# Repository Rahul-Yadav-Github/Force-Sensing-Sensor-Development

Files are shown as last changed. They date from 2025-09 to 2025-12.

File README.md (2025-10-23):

# Multi-Sensitivity Soft Tactile Sensor using Flexible Mechanical Metamaterials






---

## Project Overview

**Project Title:** Implementation of Flexible Mechanical Metamaterials Enabling Soft Tactile Sensors with Multiple Sensitivities at Multiple Force Sensing Ranges  
**Course Code:** CP302 — Honours Project  
**Institution:** Indian Institute of Technology Ropar  
**Department:** Mechanical Engineering  

**Team Members:**  
- **Rahul Yadav** — 2022MEB1334  
- **Sumer Mohan Singh Bassi** — 2022MEB1351  

**Supervisor:** Dr. Prabhat K. Agnihotri  

---

## Abstract

This project focuses on developing a **Multi-Sensitivity Soft Tactile (MST)** sensor using **flexible mechanical metamaterials**.  
The goal is to design and simulate a sensor capable of providing **multiple sensitivities across different force ranges**, overcoming the limitations of traditional single-sensitivity tactile sensors.

The sensor employs a **heterogeneous multi-layered metamaterial structure** with tunable stiffness properties, integrated with a **magnetic-based transduction mechanism** for force measurement.  
Simulations are conducted using **COMSOL Multiphysics**, combining *Solid Mechanics*, *Magnetic Fields*, and *Deformed Geometry* modules to model the mechanical and magnetic coupling behavior.

---

## Objectives

- Develop a mathematical and simulation framework for multi-sensitivity tactile sensing  
- Model a multi-layer metamaterial structure with programmable stiffness  
- Validate sensitivity and force range using multiphysics simulations  
- Demonstrate **step-by-step locking behavior** in a hierarchical structure  
- Prepare for future physical prototyping using TPU 3D printing  

---

## Methodology Summary

### 1. Mathematical Modeling
- Derived sensitivity equations based on **magnetic field variation with force**  
- Modeled metamaterial layers as **spring systems in series**  
- Established **stiffness hierarchy condition** for sequential deformation  

### 2. Simulation Framework
Implemented in **COMSOL Multiphysics** using:
- **Solid Mechanics Module:** Simulate deformation of TPU-based metamaterial  
- **Magnetic Fields Module:** Analyze field variation from embedded magnets  
- **Deformed Geometry Module:** Couple mechanical deformation with magnetic response  

### 3. Validation
Simulation outputs (force–displacement and magnetic variation plots) were validated against literature (Mohammadi et al., *Sci. Rep.*, 2021).

**Target sensitivities and ranges:**
| Layer | Sensitivity (N⁻¹) | Force Range (N) |
|:---|:---:|:---:|
| 1 | 0.26 | 0.9 |
| 2 | 0.08 | 4.8 |
| 3 | 0.03 | 16.2 |

---

## CAD Design

The metamaterial **unit cell** and **three-layer assembly** were modeled in SolidWorks and exported as STL files for fabrication and analysis.

- **Material:** Thermoplastic Polyurethane (TPU), Shore Hardness A85  
- **Design Parameters:**  
  - θ = (25°, 33°, 37°)  
  - t = (0.6, 1.0, 1.4) mm  
  - h = (2.0, 2.8, 3.5) mm  
--- 

## Repository Contents
- `docs/` → Project report and references  
- `cad_design/` → STL files and renders of the metamaterial design  
- `comsol_model/` → Multiphysics simulation model and results

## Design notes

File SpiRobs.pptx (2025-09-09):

## SpiRobs

Overview

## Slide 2

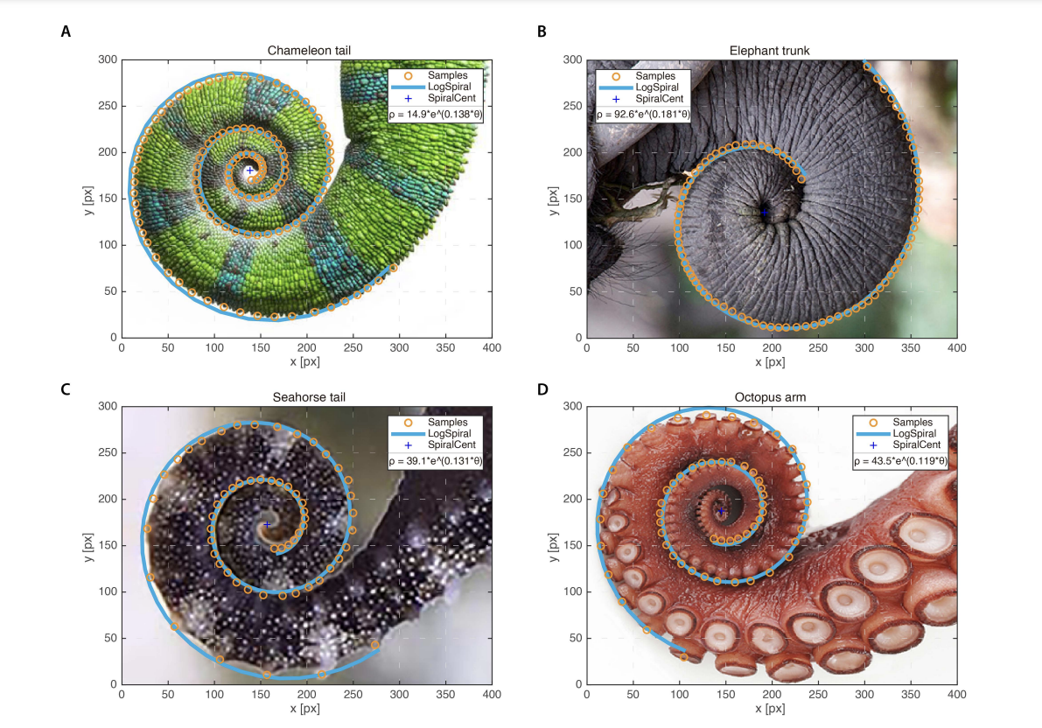
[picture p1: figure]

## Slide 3

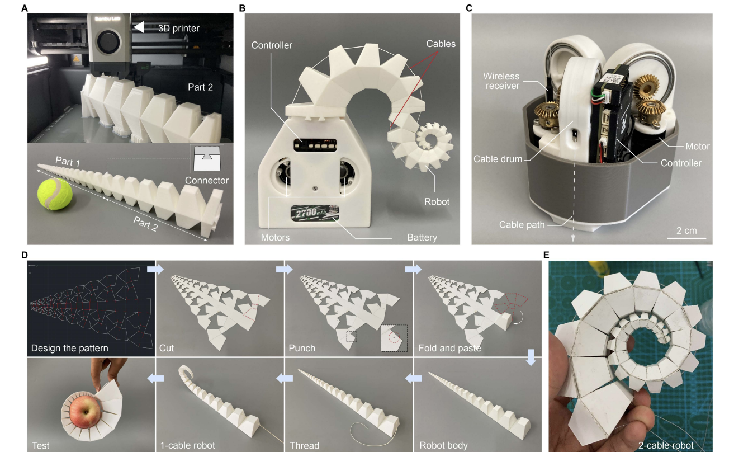
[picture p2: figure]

## Paper 1 Overview

- replicate the logarithmic spiral
- actuated by cables, which allows for fast and life-like movements.
- miniaturized gripper, a manipulator mounted on a drone, and multi-robot arrays.

## Existing Designs Problems

- different actuation methods, including pneumatic16–18 and cable driven, most of these prototypes can only produce arc-shaped bends with a limited curvature at the tip.
- use of soft materials (such as silicone) can increase the bending range and improve flexibility, this may result in wrinkling and buckling under large actuation forces, which, in turn, means failure to maintain a firm grasp.
- passive deformation caused by interacting with objects, However, these robots can typically only produce a single repetitive pattern (such as bend and release).

## What is required

- passive deformation caused by interacting with objects.
- ‘‘universal’’ strategies for reaching, grasping, and transporting objects of different shapes and from different positions (in contrast to rigid robots, albeit at the cost of high complexity for planning and control).

## Two Principles

- universal (across scales) design based on discretizing and uncurling the logarithmic spiral.
- Discretizing the Spiral - Instead of treating the spiral as a continuous smooth curve, the researchers break it into small connected sections (or discrete segments).
- Uncurling Mechanism - When the spiral is uncurling, these discrete segments move relative to each other in a coordinated manner.
- grasping strategy, inspired by the octopus
- controlling the curling/uncurling motion using cables
- passive deformation upon contact to adapt to objects of variable shapes and sizes (e.g., cup, pen, egg, strawberry, pineapple, and more;

## Design of SpiRobs

- Logarithmic Spiral
- Discretization
- Elastic Layer
- Taper Angle
- Conclusions are drawn for fixed length and tip diameter
- The smaller the taper angle, the larger the workspace
- At the same time, the larger the taper angle, the smaller the diameter of the smallest object that can be grasped and the larger the maximum load capacity.
- Taking the robot with a taper angle of 15 as an example, it can grasp objects whose diameters vary by two orders of magnitude (from 5.6 to 115 mm) and weigh roughly 260 times the weight of the robot (38.4 g selfweight and 10 kg load capacity

## Bioinspired grasping strategy

- Octopus- it progressively uncurls and straightens curled arms to reach the target. After making contact with the object, the arm keeps uncurling on the surface of the object to align the suckers.

## Automation

- To automate the grasping, they propose a method to detect contact with an object as well as a simple rule (piece-wise linear actuation) to control the cable forces by relating them directly to the object’s position.
- The threshold for detection was set through multiple experiments, and this simple mechanism was shown to be capable of detecting even the slightest contact; e.g., with a feather.

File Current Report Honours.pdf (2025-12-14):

# Honours Project Report Course Code: CP304

# Implementation of Flexible Mechanical Metamaterials Enabling Soft Tactile Sensors with Multiple Sensitivities at Multiple Force Sensing Ranges

### Team Members: Rahul Yadav (2022MEB1334) Sumer Bassi (2022MEB1351)

### Supervisor: Dr Prabhat K. Agnihotri Department: Mechanical Indian Institute Of Technology Ropar

### November 25, 2025

## Contents

1 Abstract | 4
2 Introduction | 4
3 Mathematical Theory and Formulations | 4
4 Background / Literature Review | 8
5 Problem Statement/Aim | 10
6 Methodology | 11

7 CAD Design and Modeling | 13
8 COMSOL Multiphysics Simulation Results | 15
9 Evolution of Methodology and Coupling Challenges | 25
10 Neccessary Plots for further calculations | 28
10.3 Normalized Magnetic Flux Density Change vs Magnet Displacement . . . | 29

### 11 Extraction of Layer Stiffness ki and Sensitivity Si from Simulation Data 31

12 Comparison Plot | 36
13 Future Work | 37
14 Conclusion | 38

## 1 Abstract

This project focuses on the development of a novel Multi-sensitivity Soft Tactile (MST) sensor based on flexible mechanical metamaterials. The primary objective is to design, model, and simulate a sensor that provides multiple sensitivities across different force sensing ranges, overcoming the traditional limitation of single-sensitivity tactile sensors. The proposed design utilizes a heterogeneous multi-layered structure with tunable stiffness properties, integrated with magnetic-based transduction method for force measurement.
The mechanical metamaterial structure consists of collapsible layers that exhibit stepby-step locking behavior, enabling different sensitivity regimes at various force magnitudes. This project involves CAD design, mathematical modeling, and COMSOL Multiphysics simulation of the metamaterial structure, aiming to demonstrate the feasibility of creating tactile sensors with programmable sensitivity characteristics for applications in robotics, prosthetics, and human-machine interaction.

## 2 Introduction

Tactile sensing is a fundamental requirement for advanced robotic systems, prosthetic devices, and human-machine interfaces. Traditional tactile sensors are typically designed with fixed sensitivity and operate within a predetermined force range, limiting their versatility in real-world applications. The need for adaptive tactile sensing capabilities has grown significantly with the advancement of soft robotics and the demand for more sophisticated human-robot interactions.
Modern applications such as robotic manipulation, texture identification, slip detection, and in-hand manipulation require tactile sensors capable of operating with different sensitivities across multiple force ranges. Current soft tactile sensors face inherent trade-offs between sensitivity and sensing range, where high sensitivity is achieved at narrow force ranges or low sensitivity across wide force ranges.
This project addresses these limitations by developing a novel approach based on flexible mechanical metamaterials that can provide multiple predetermined sensitivities at different force sensing ranges. The approach is inspired by human tactile sensing capabilities, where the skin’s multi-layered structure with varying stiffness properties enables sophisticated touch perception.
The current phase of development involves designing, modeling, and simulating a Multi-sensitivity Soft Tactile (MST) sensor that utilizes mechanical metamaterials as the force transfer medium, integrated with magnetic-based transduction for displacement measurement and force calculation.

## 3 Mathematical Theory and Formulations

### 3.1 Fundamental Sensitivity Definition

Based on the original research by Mohammadi et al. (2021), the core mathematical foundation of the MST sensor begins with the definition of sensitivity in terms of magnetic field variation with respect to applied force. The sensitivity S is mathematically defined as:

S =

∆B/B0
∆F

[N

−1
] | (1)

where:
- S = Sensitivity of the sensor (inverse Newtons)
- ∆B = Change in magnetic field magnitude (Tesla)
- B0 = Initial magnetic field without applied force (Tesla)
- ∆F = Change in applied force (Newtons)

This fundamental equation establishes the relationship between the measurable magnetic field changes and the applied forces, forming the basis for all subsequent calculations.

### 3.2 Multi-Layer Mechanical Model

### 3.2.1 Spring Model Analogy

The metamaterial structure can be mathematically modeled as a system of springs in series, where each unit cell i in block j acts as a spring with stiffness kji. For a single block with i layers, the force-displacement relationship for each unit cell follows Hooke’s law:

Fi = ki

- di | (2)

where:
- Fi = Force acting on the i th unit cell (N)
- ki = Stiffness of the i
th unit cell (N/mm)
- di = Displacement of the i
th unit cell (mm)

### 3.2.2 Stiffness Hierarchy Condition

For proper step-by-step locking behavior, the unit cells must be arranged in ascending order of stiffness:

kj1 ≪ kj2 ≪ · · · ≪ kji | (3)

This condition ensures that the softest layer deforms first, followed by progressively stiffer layers as the applied force increases.

### 3.3 Layer-Specific Sensitivity Calculation

For each individual layer i in the multi-layered structure, the sensitivity can be expressed as:

Si =

(∆B/B0)/∆di
ki

[N

−1
] | (4)

This equation demonstrates that the sensitivity of each layer depends on:
- The magnetic field gradient with respect to displacement (∆B/B0)/∆di
- The mechanical stiffness of the unit cell ki

### 3.4 Force Sensing Range Determination

The force sensing range for each layer i is mathematically defined as:

Ri = dmaxi × ki

[N] | (5)

where:

- Ri = Force sensing range of the i
th layer (N)
- dmaxi = Maximum displacement of the i th unit cell before locking (mm)
- ki = Stiffness of the i
th unit cell (N/mm)

### 3.5 Magnetic Field-Displacement Relationship

### 3.5.1 General Functional Form

The relationship between magnetic field magnitude and permanent magnet displacement can be represented by a function:

B = f(d) | (6)

where:

- B = Magnetic field magnitude (Tesla)
- d = Displacement of permanent magnet (mm)

The specific functional form depends on the magnetic system configuration and can be determined through simulation or experimental measurement.

### 3.5.2 Normalized Magnetic Field Variation

The normalized change in magnetic field is calculated as:

∆B
B0

=

B(d) − B0 B0 | (7)

The gradient of this relationship provides the displacement sensitivity:

∂

∂d
∆B
B0
(8)

### 3.6 Complete Sensitivity Calculation Process

### 3.6.1 Step-by-Step Calculation Method

The complete process for calculating multi-layer sensitivity involves the following steps:
Step 1: Determine Individual Layer Stiffnesses
Using finite element analysis or experimental testing, determine the stiffness values:

k1 = f(θ1, t1, h1, D1, H1, W1) | (9)
k2 = f(θ2, t2, h2, D2, H2, W2) | (10)
k3 = f(θ3, t3, h3, D3, H3, W3) | (11)

where θ, t, and h are the tuning parameters, and D, H, W are the overall dimensions.
Step 2: Calculate Maximum Displacements
For each layer, determine the maximum displacement before locking occurs:
dmaxi = f(unit cell geometry) | (12)
Step 3: Determine Force Ranges
Calculate the force range for each layer using Equation (5):
R1 = dmax1 × k1 | (13)
R2 = dmax2 × k2 | (14)
R3 = dmax3 × k3 | (15)
Step 4: Calculate Magnetic Field Gradients
For each displacement range, calculate the magnetic field gradient through simulation or measurement:
∆B
B0

i

= f(magnetic system configuration) | (16)
Step 5: Compute Final Sensitivities Apply Equation (4) to obtain the for each layer:

Si =

(∆B/B0)i/∆di
ki

(17)

### 3.7 Design Parameters from Literature

Based on the example provided in Mohammadi et al. (2021), the following design parameters were used:
Optimized Design Parameters:
θ = (25, 33, 37) | (18)
t = (0.6, 1.0, 1.4) mm | (19)
h = (2.0, 2.8, 3.5) mm | (20)

Resulting Performance:

Sensitivities: S = (0.26, 0.08, 0.03) N⁻¹
(21)
Force ranges: R = (0.9, 4.8, 16.2) N | (22)

## 4 Background / Literature Review

### 4.1 Tactile Sensing Technologies

Tactile sensing has been extensively researched with various transduction mechanisms, each presenting unique advantages and limitations for multi-range sensing applications.

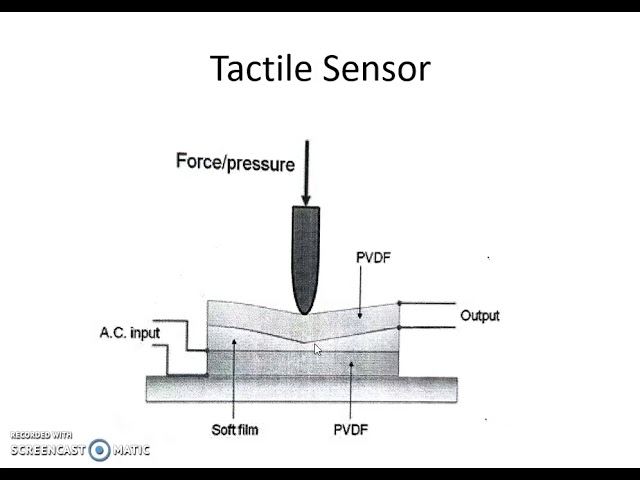
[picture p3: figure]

Figure 1: General tactile sensor structure

### 4.1.1 Resistive and Piezoresistive Sensors

Piezoresistive materials change their electrical resistance under deformation. Good sensitivity but issues like hysteresis and drift [1].

Figure 2: Piezoresistive tactile sensor

### 4.1.2 Capacitive Tactile Sensors

Measure capacitance change due to deformation; excellent linearity but sensitive to noise and environment [2].

Figure 3: Capacitive tactile sensor

### 4.1.3 Optical Tactile Sensors

Light-based deformation sensing; high accuracy but bulky and expensive [3].

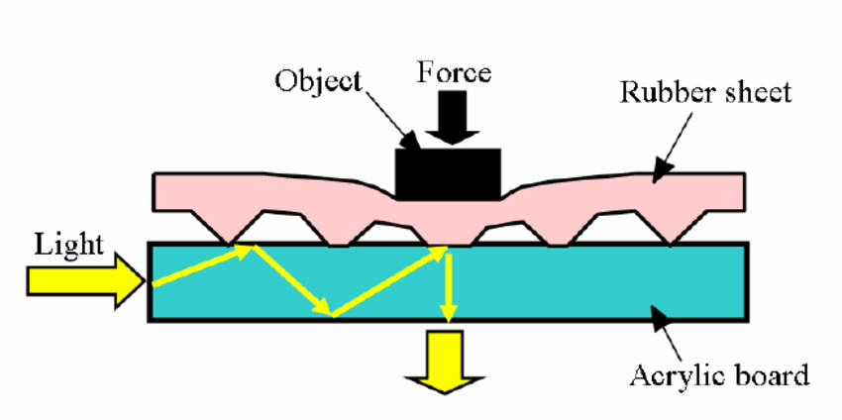
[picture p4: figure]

Figure 4: Optical tactile sensor

### 4.1.4 Magnetic-Based Tactile Sensors

Magnet + magnetometer based sensing; stable, drift-resistant, and suitable for soft robotics [4].

Figure 5: Magnetic tactile sensor

### 4.2 Mechanical Metamaterials

Mechanical metamaterials are artificially structured materials whose mechanical properties are determined by their geometric structure rather than their constituent materials. These materials offer unprecedented control over mechanical properties through structural design.
Key characteristics of mechanical metamaterials include:
- Programmable stiffness and deformation patterns
- Ability to achieve properties not found in natural materials
- Scalable manufacturing through additive manufacturing
- Tunable mechanical responses through geometric parameters

### 4.3 Multi-Range Sensing Approaches

Several approaches have been developed to extend the sensing range while maintaining sensitivity:
Hierarchical Structures: Multi-level microstructures that provide different mechanical responses at various force levels.
Intrafillable Architectures: Structures with graded stiffness properties that compress progressively under increasing loads.
Pressure-Peak Effects: Utilization of structural instabilities to create non-linear force-displacement relationships.
However, these approaches typically provide limited control over sensitivity characteristics and cannot achieve arbitrary predetermined sensitivity profiles.

### 4.4 Research Gap

Despite advances in tactile sensing technology, there remains a significant gap in developing sensors that can provide:

- Multiple arbitrary predetermined sensitivities
- Programmable force sensing ranges
- Simple manufacturing processes
- Integration flexibility for various applications

This project addresses these gaps by developing the MST sensor concept based on flexible mechanical metamaterials.

## 5 Problem Statement/Aim

### 5.1 Problem Statement

Existing soft tactile sensors are limited to single predetermined sensitivity and force sensing range, which restricts their applicability in complex real-world scenarios. Applications such as robotic manipulation, prosthetic control, and health monitoring require tactile sensors that can adapt their sensitivity based on the interaction context and force magnitude.
The main challenges include:
1. Limited Sensitivity Range: Traditional sensors cannot provide high sensitivity across wide force ranges
2. Fixed Characteristics: Sensor sensitivity and range are predetermined during design and cannot be modified
3. Trade-off Constraints: Existing designs face inherent trade-offs between sensitivity and sensing range
4. Manufacturing Complexity: Multi-sensitivity sensors often require complex fabrication processes

### 5.2 Aim and Objectives

Primary Aim: To develop and simulate a Multi-sensitivity Soft Tactile (MST) sensor based on flexible mechanical metamaterials that can provide multiple predetermined sensitivities at different force sensing ranges.
Specific Objectives:
1. Develop the mathematical framework and design equations for the metamaterial structure
2. Implement systematic calculation procedures for sensitivity and range determination

3. Design and optimize CAD models using the derived mathematical relationships
4. Develop multi-physics simulation models in COMSOL for validating the theoretical calculations
5. Simulate and analyze the force-displacement characteristics and sensitivity profiles
6. Create and validate the step-by-step locking mechanism through mathematical modeling and FEA
7. Develop the integration approach for the magnetic-based transduction system
8. Create a comprehensive design methodology based on mathematical foundations
9. Prepare for subsequent experimental validation and performance evaluation

## 6 Methodology

### 6.1 Integrated Design and Simulation Methodology

This project employs a comprehensive methodology that integrates theoretical design, computational simulation, and systematic validation to develop the MST sensor system. The approach is structured to ensure seamless transition from mathematical concepts to practical implementation.

### 6.2 Phase 1: Design Requirements and Specifications

### 6.2.1 Target Performance Based on Literature

Based on the research by Mohammadi et al. (2021), the target specifications are: Target Sensitivities and Ranges:

- Layer 1: Sensitivity S1 = 0.26 N⁻¹
, Range R1 = 0.9 N
- Layer 2: Sensitivity S2 = 0.08 N⁻¹ , Range R2 = 4.8 N
- Layer 3: Sensitivity S3 = 0.03 N⁻¹
, Range R3 = 16.2 N

### 6.2.2 Material and Manufacturing Specifications

Based on the original research:

- Material: Thermoplastic Polyurethane (TPU) with Shore hardness A85
- Manufacturing: 3D printing using standard benchtop printers
- Magnet specifications: Disc-shape Neodymium gold coated magnet, diameter 6 mm, thickness 2 mm, remanent magnetization 1.3 T
- Magnetometer: Tri-axis magnetometer (MLX90393, Melexis Inc.) with sensitivity 6211 mT⁻¹ and resolution 0.161 µT

### 6.3 Phase 2: Multi-Physics Simulation Framework

### 6.3.1 COMSOL Multiphysics Implementation Strategy

The simulation framework employs coupled physics modules to capture the complete sensor behavior:

### 1. Solid Mechanics Module

- Purpose: Analyze mechanical deformation of metamaterial unit cells under applied forces
- Material Model: Hyperelastic model appropriate for TPU material
- Boundary Conditions: Fixed constraint at base, prescribed displacement or force at top surface

### 2. Magnetic Fields Module

- Purpose: Calculate magnetic field distribution and variations due to magnet displacement
- Magnet Model: Permanent magnet with specifications matching experimental setup
- Boundary Conditions: Magnetic insulation on outer boundaries

### 3. Deformed Geometry Module

- Purpose: Couple mechanical deformation with magnetic field changes
- Implementation: Automatic re-meshing based on structural displacement

### 6.3.2 Simulation Workflow

Step 1: Individual Unit Cell Characterization
1. Create parametric 3D models of unit cells with tuning parameters (θ, t, h)
2. Perform compression simulations under various loading conditions
3. Extract force-displacement data and calculate stiffness values
4. Develop relationships between geometric parameters and stiffness
Step 2: Multi-Layer Assembly Simulation
1. Assemble three-layer system using literature-based parameters
2. Apply progressive loading to demonstrate locking behavior
3. Validate step-by-step compression mechanism
4. Measure individual layer deformation contributions
Step 3: Magnetic System Integration
1. Position permanent magnet within deformable structure

2. Simulate magnetic field distribution for undeformed state
3. Calculate field variations during mechanical deformation
4. Map magnetic field magnitude vs. displacement relationships
Step 4: Coupled Multi-Physics Analysis
1. Execute fully coupled mechanical-magnetic simulation
2. Apply force loads across the expected operating range
3. Extract displacement and magnetic field data simultaneously
4. Calculate sensitivity values using the fundamental equation

### 6.4 Phase 3: Design Validation and Analysis

### 6.4.1 Parameter Validation

Validate the simulation framework using the known design parameters:

θ = (25, 33, 37) | (23)
t = (0.6, 1.0, 1.4) mm | (24)
h = (2.0, 2.8, 3.5) mm | (25)

### 6.4.2 Performance Verification

Compare simulation results with the expected performance:

Target Sensitivities: S = (0.26, 0.08, 0.03) N⁻¹
(26)
Target Force ranges: R = (0.9, 4.8, 16.2) N | (27)

## 7 CAD Design and Modeling

### 7.1 Unit Cell Design

The unit cell design is based on the mathematical relationships and parameters from the literature. Each unit cell is designed with specific geometric parameters to achieve target stiffness values.
Design Parameters from Literature:
- Depth (D): 20 mm
- Height (H): 5 mm
- Width (W): 30 mm
- Tuning parameters: θ, t, h as specified above

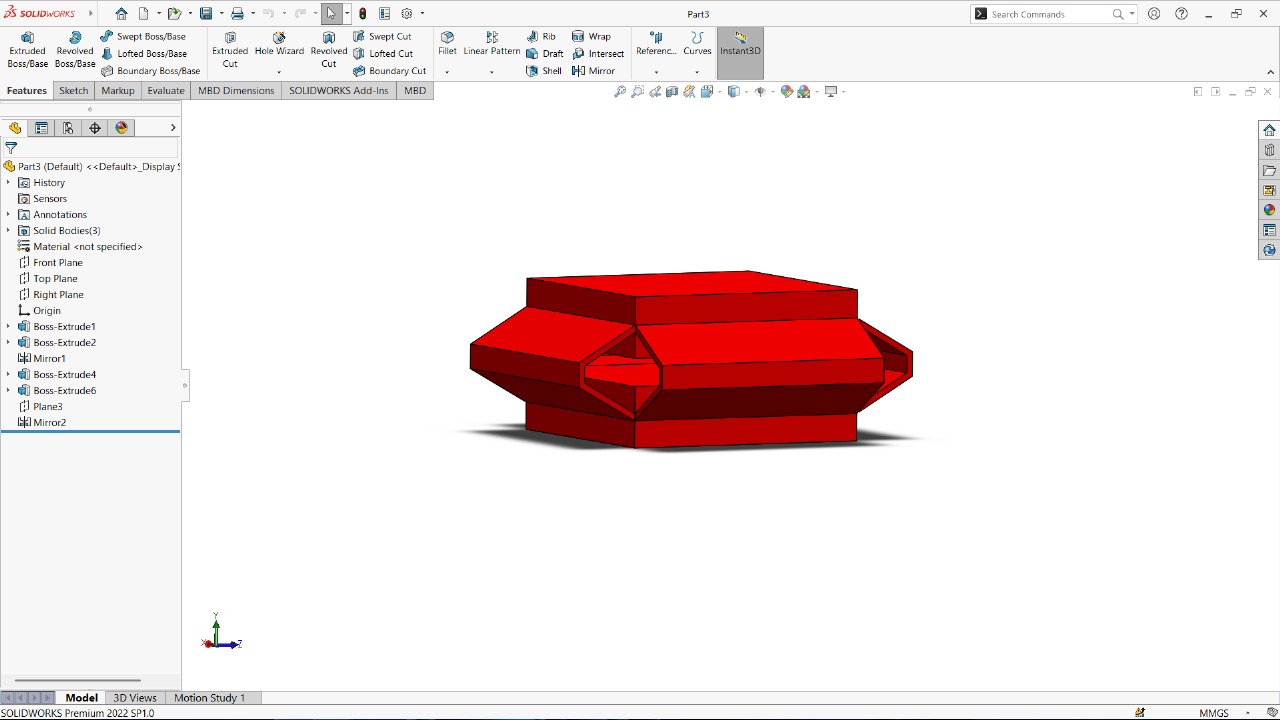
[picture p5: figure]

Figure 6: Single unit cell design showing the internal collapsible structure and geometric parameters. The strut architecture enables controlled deformation characteristics under applied loads.

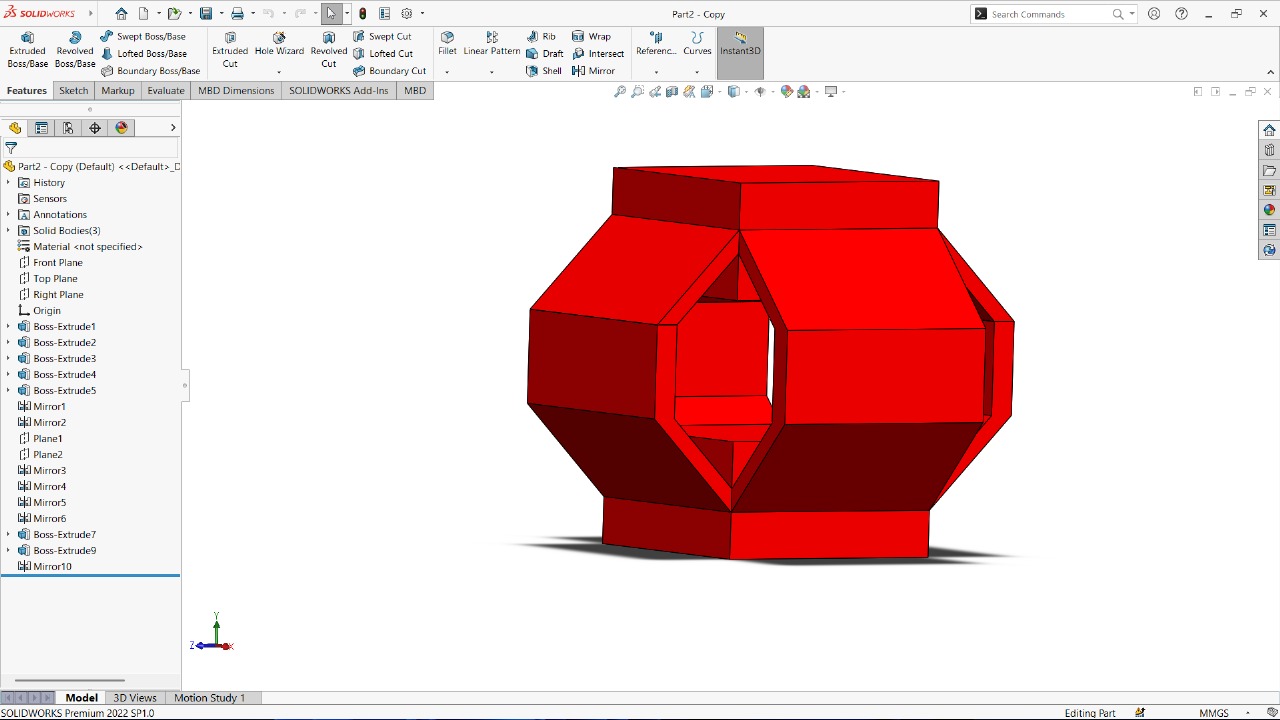
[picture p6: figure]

Figure 7: Unit Cell Configurations at Different Geometric Dimension.

### 7.2 Multi-Layer Assembly

The multi-layer assembly follows the design approach from Mohammadi et al. (2021): Assembly Configuration:

- Three-layer structure with ascending stiffness values
- Integrated permanent magnet housing in top layer
- Magnetometer housing in base structure
- Proper spacing for mechanical coupling and magnetic field measurement

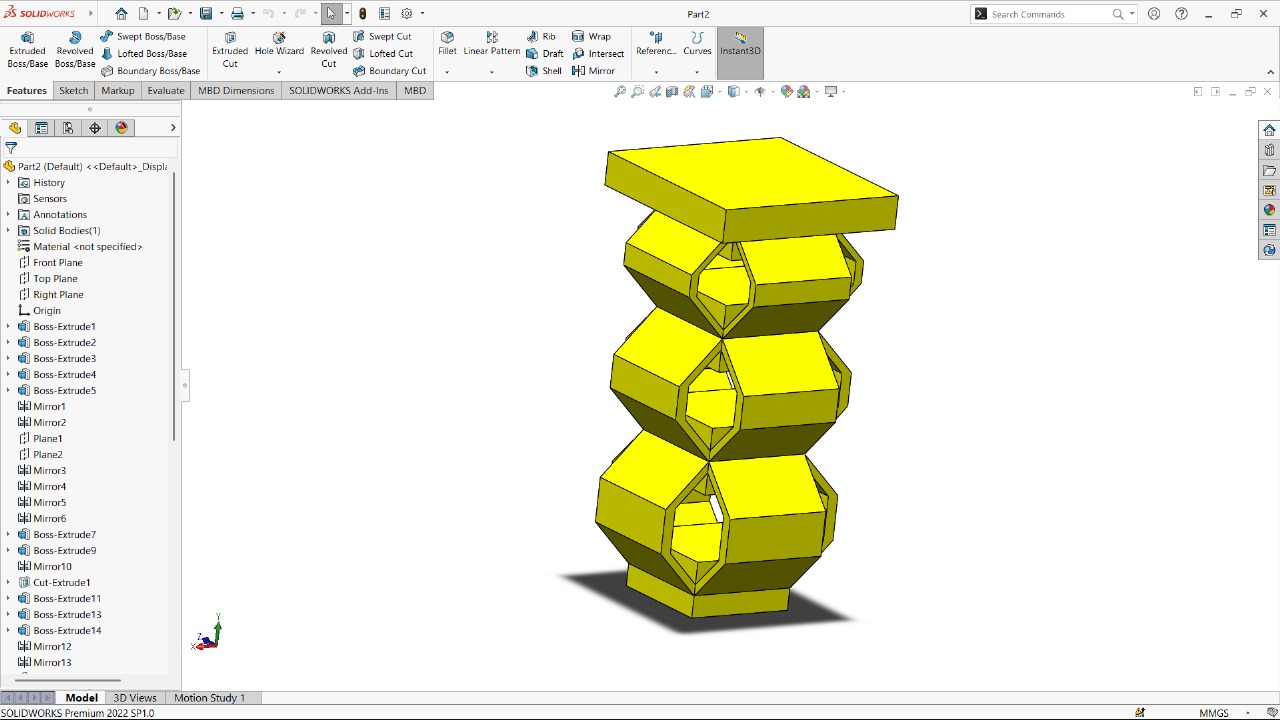
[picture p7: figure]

Figure 8: Complete three-layer metamaterial structure showing stacked unit cells with different stiffness properties. The assembly demonstrates the hierarchical arrangement with progressively increasing stiffness from bottom to top layer.

## 8 COMSOL Multiphysics Simulation Results

This section presents the comprehensive simulation results obtained from COMSOL Multiphysics, covering 2D axisymmetric models, 3D validation models, and fully coupled multiphysics simulations.

### 8.1 2D Axisymmetric Magnet Simulation

### 8.1.1 Objective

To simulate the magnetic field strength (B⃗ ) from a cylindrical magnet at a point on its central axis. The simulation plots the magnetic field magnitude as a function of the vertical distance (z disp) between the magnet and the sensor point using a computationally efficient 2D-Axisymmetric model.

### 8.1.2 Methodology

The simulation was performed using a Stationary study with a Parametric Sweep.

1. Model Setup: A 2D-Axisymmetric model was chosen. The Magnetic Fields (mf ) physics interface was added.
2. Study: A Stationary study was selected.
3. Parameters: Global parameters were defined for magnet radius (r mag), height (h mag), and the initial magnetometer distance (z dist).
4. Geometry: The geometry was built in the r-z plane. A rectangle represented the magnet, a larger rectangle represented the surrounding air, and a point at the origin (0, 0) represented the magnetometer.
5. Materials: Air was applied to the air domain, and NdFeB N35 (or similar) was applied to the magnet domain.

6. Physics: An Amp`ere’s Law node was added to the magnet domain, configured with a Remanent flux density B⃗

r (e.g., B⃗
r = (0, −1.2 [T])).
7. Study Setup: A Parametric Sweep was added to the Stationary study. The sweep was configured to vary the z dist parameter from a large value (e.g., 50 mm) to a small value (e.g., 5 mm).
8. Data Extraction: A 1D Plot Group was created. A Point Graph was added, selecting the magnetometer point at (0, 0). The y-axis expression was set to mf.normB (magnetic flux density norm) and the x-axis was set to the parameter z dist.

### 8.1.3 Results

The simulation provides both a 2D visualization of the magnetic field at different distances and the desired 1D plot of field strength versus distance.

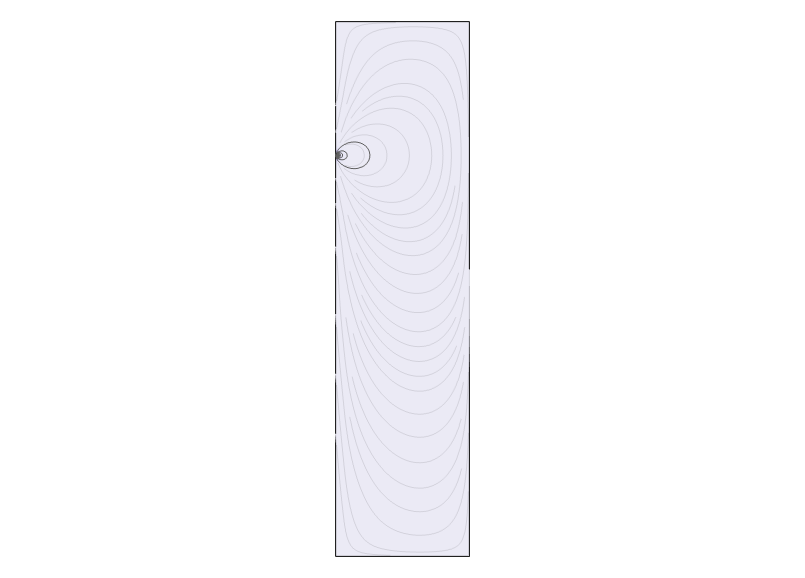
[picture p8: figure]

(a) Magnetic field at z disp = 50 mm. | (b) Magnetic field at z disp = 5 mm.

Figure 9: 2D Axisymmetric simulation showing the magnetic flux density (mf.normB) at initial and final magnet-sensor distances. The field is significantly stronger at closer proximity.

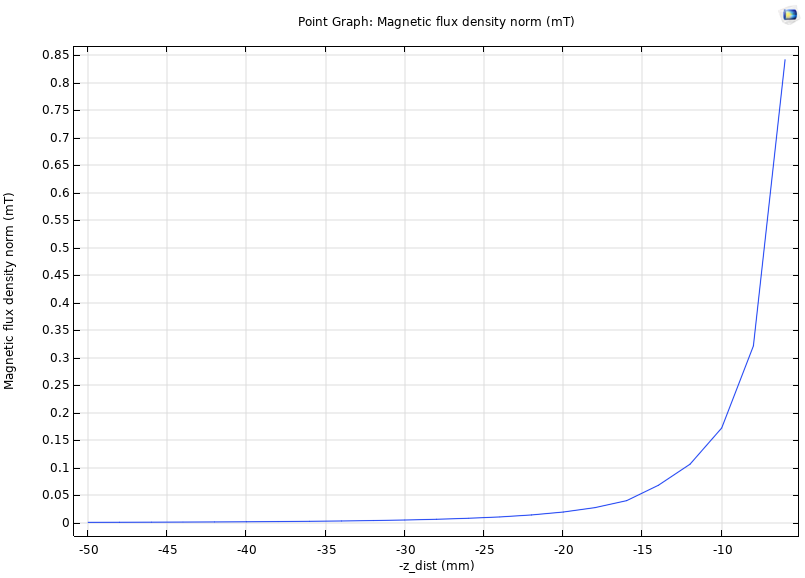
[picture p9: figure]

Figure 10: Magnetic field strength at the magnetometer as a function of vertical distance (z disp) in the 2D model. The field strength increases exponentially as the distance decreases.

### 8.2 3D Magnet Simulation

### 8.2.1 Objective

To validate the 2D-Axisymmetric model and to serve as a baseline for the full multiphysics model. This simulation replicates the 2D setup in a full 3D space.

### 8.2.2 Methodology

The process is nearly identical to the 2D model, but with 3D geometry.

1. Model Setup: A 3D model was chosen, adding Magnetic Fields (mf ) and a Stationary study.
2. Parameters: Same parameters: r mag, h mag, z dist.
3. Geometry: A Cylinder was created for the magnet and a large Sphere for the air domain. A Point at (0, 0, 0) was added for the magnetometer.
4. Physics: An Amp`ere’s Law node was applied to the cylinder domain with B⃗
r =
(0, 0, −1.2 [T]).
5. Study Setup: A Parametric Sweep was used to vary z dist.
6. Data Extraction: A 1D Plot Group was used to plot mf.normB at the magnetometer point against the z dist parameter.

### 8.2.3 Results

The 3D model results confirm the findings of the 2D model, as expected for a measurement on the central axis.

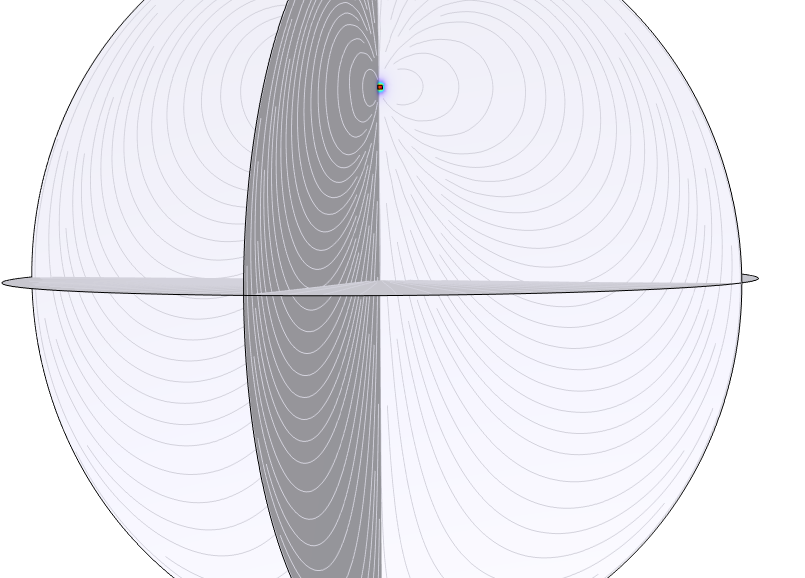
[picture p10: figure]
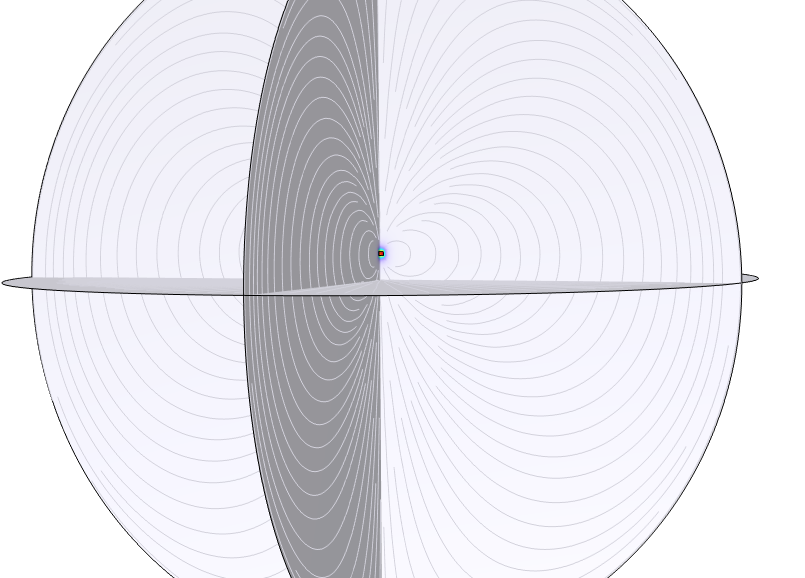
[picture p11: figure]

(a) Magnetic field at z disp = 50 mm. | (b) Magnetic field at z disp = 5 mm.

Figure 11: 3D simulation showing the magnetic flux density (mf.normB) on a slice plane at initial and final magnet-sensor distances. The increase in field strength at closer distances is clearly visible.

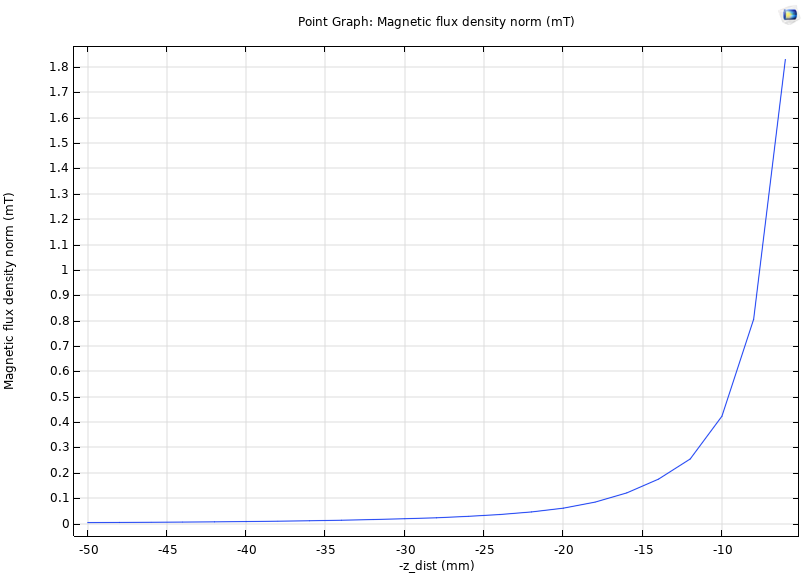
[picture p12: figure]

Figure 12: Magnetic field strength vs. vertical distance (z disp) from the 3D model. This plot should be identical to the 2D-axisymmetric result.

### 8.3 3D Coupled Multiphysics Simulation

### 8.3.1 Objective (Cell Structure)

To create a fully coupled model simulating a force-sensing device. An applied force deforms a structure, reducing the distance between an attached magnet and a fixed magnetometer. The goal is to plot the measured magnetic field as a function of displacement, and subsequently, to create a calibration curve to determine the applied force from a change in magnetic field.

### 8.3.2 Methodology (Cell Structure)

This model couples Solid Mechanics (solid), Magnetic Fields (mf ), and Moving Mesh (ale). We use a prescribed displacement sweep, which is more stable than a force sweep and directly gives us the plot we need. We then extract the reaction force to find the force-to-field relationship.

1. Model Setup: A 3D model was created, adding:
- Solid Mechanics (solid)
- Magnetic Fields (mf )
- Moving Mesh (ale)
2. Study: A Stationary study with a Parametric Sweep was added.
3. Parameters: A parameter y disp was created with a value of 0[mm]. This will be our sweep parameter.
4. Geometry: The custom structure was imported. The magnet was partitioned as a separate domain on top. A large air domain (sphere or box) was created around the structure. A point was added to the bottom fixed face for the magnetometer.
5. Materials: Air, NdFeB N35 (with mechanical properties like Young’s Modulus added), and a structural material (e.g., Silicone) were applied to their respective domains.
6. Physics (Solid Mechanics):
- A Fixed Constraint was applied to the bottom face of the structure.
- A Prescribed Displacement node was applied to the top face, with the ydisplacement set to the variable y disp.
7. Physics (Moving Mesh):
- Prescribed Mesh Displacement (1): Applied to the solid domains (structure + magnet), with displacement set to dx=solid.u, dy=solid.v, dz=solid.w.
- Free Deformation: Applied to the Air domain.
- Prescribed Mesh Displacement (2): Applied to the outer air boundaries, with displacements set to 0 to keep them fixed.
8. Physics (Magnetic Fields):

- Amp`ere’s Law was applied to the magnet domain with a remanent flux density (e.g., B⃗
r = (0, −1.2 [T], 0)).
- Crucial Step: In the Discretization section, the Spatial frame was changed to Mesh (ale).
9. Study Setup: A Parametric Sweep was configured to sweep the y disp parameter from 0[mm] to -5[mm].
10. Data Extraction:
- 2D/3D plots were generated for stress (solid.mises) and magnetic field (mf.normB).
- A 1D Plot Group was created to plot mf.normB (at the magnetometer) vs. the parameter y disp.
- A second 1D Plot Group was created to find the force, plotting the reaction force solid.RFy vs. mf.normB.

### 8.4 Results (Cell Structure)

The simulation shows the deformation of the structure and the corresponding change in the magnetic field.

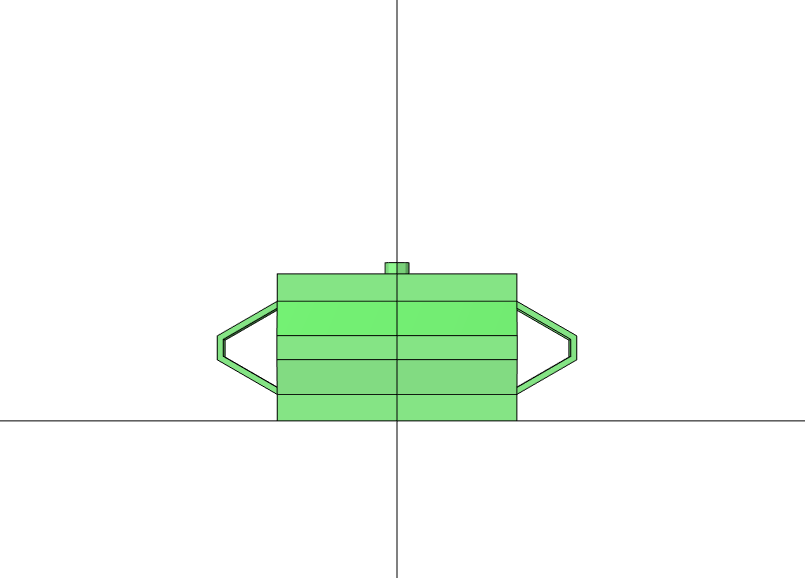
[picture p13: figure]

(a) Initial solid deformation (von Mises stress) at y disp = 0.

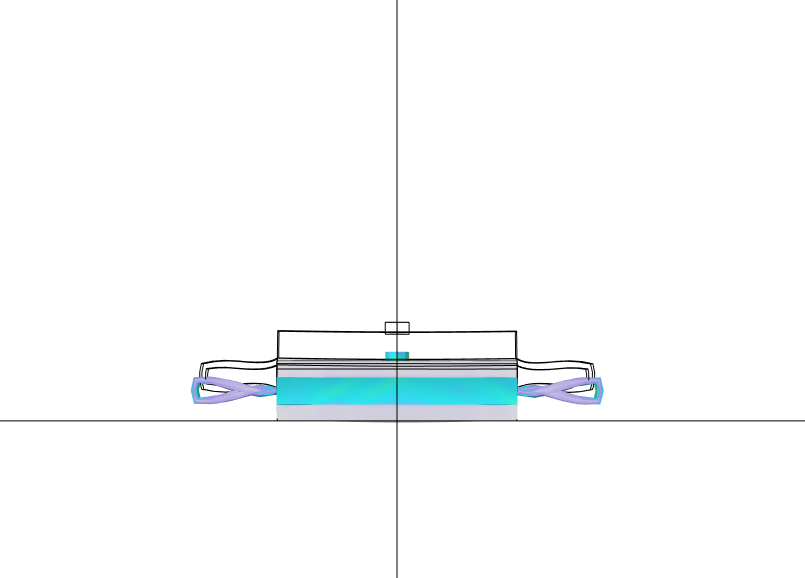
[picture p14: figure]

(b) Final solid deformation (von Mises stress) at y disp = -5 mm.

Figure 13: Solid mechanics simulation showing stress distribution at initial and final displacement.

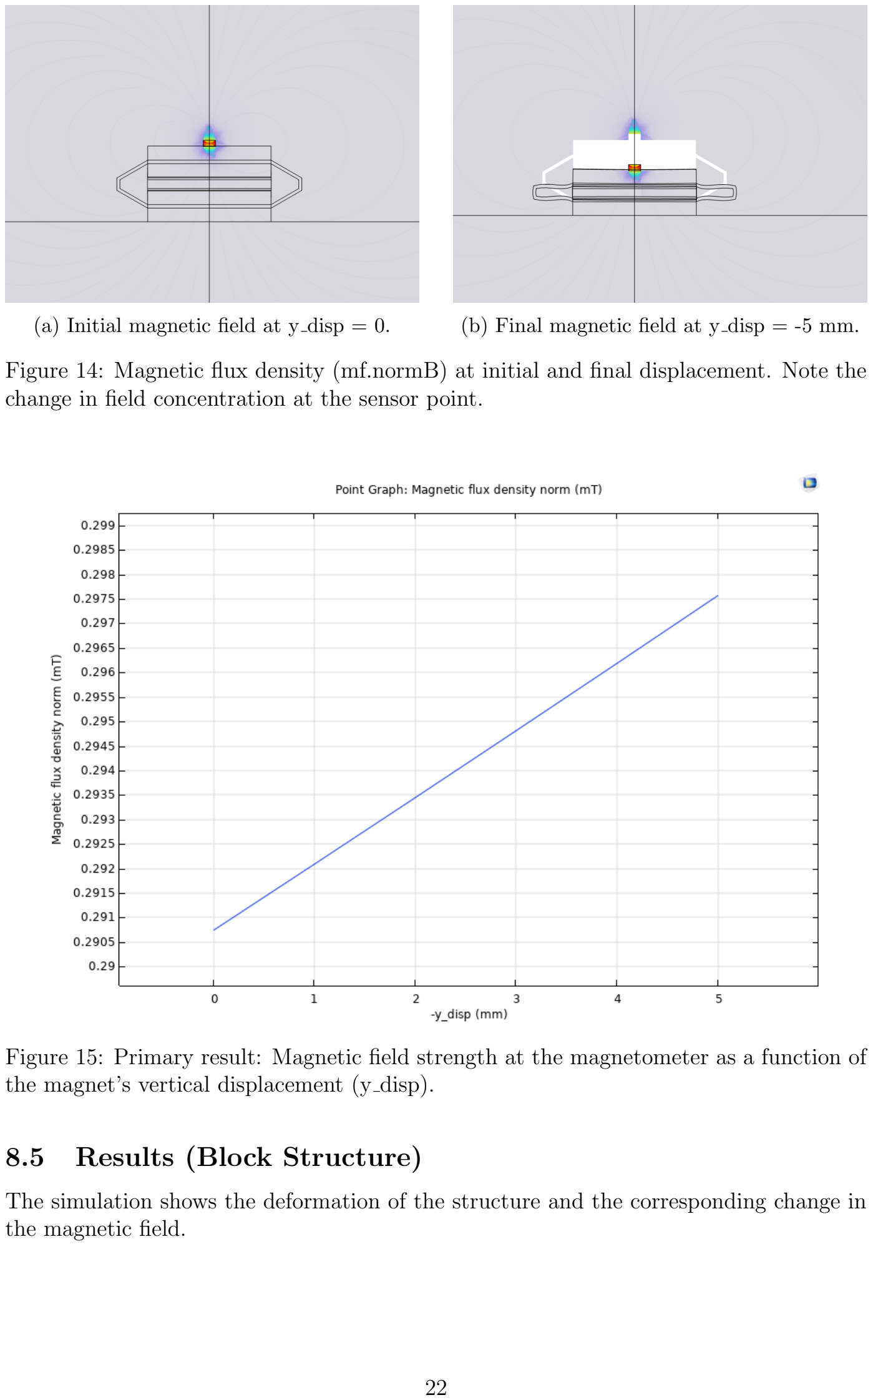
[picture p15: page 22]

(a) Initial magnetic field at y disp = 0. | (b) Final magnetic field at y disp = -5 mm.

Figure 14: Magnetic flux density (mf.normB) at initial and final displacement. Note the change in field concentration at the sensor point.

Figure 15: Primary result: Magnetic field strength at the magnetometer as a function of the magnet’s vertical displacement (y disp).

### 8.5 Results (Block Structure)

The simulation shows the deformation of the structure and the corresponding change in the magnetic field.

(a) Initial solid deformation (von Mises stress) at y disp = 0.

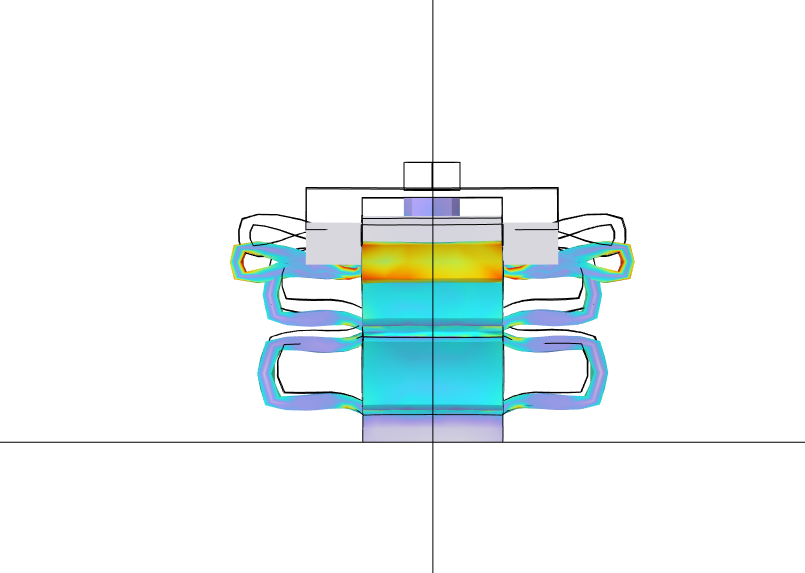
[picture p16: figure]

(b) Final solid deformation (von Mises stress) at y disp = -15 mm.

Figure 16: Solid mechanics simulation showing stress distribution at initial and final displacement.

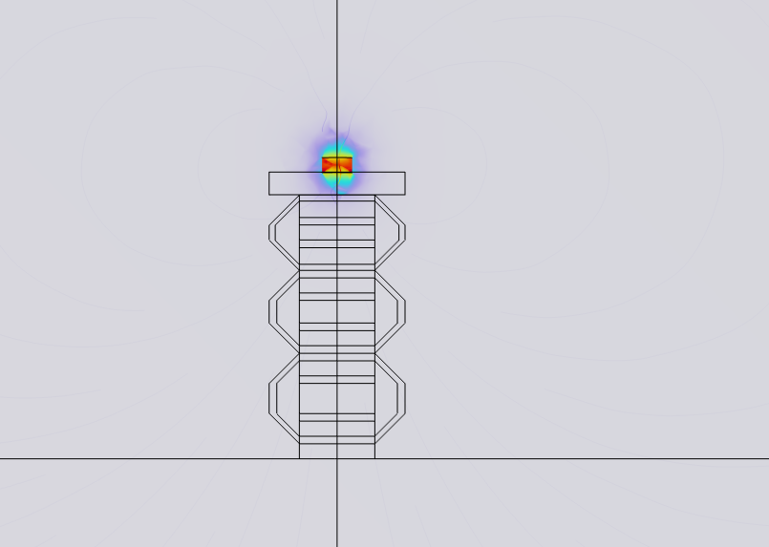
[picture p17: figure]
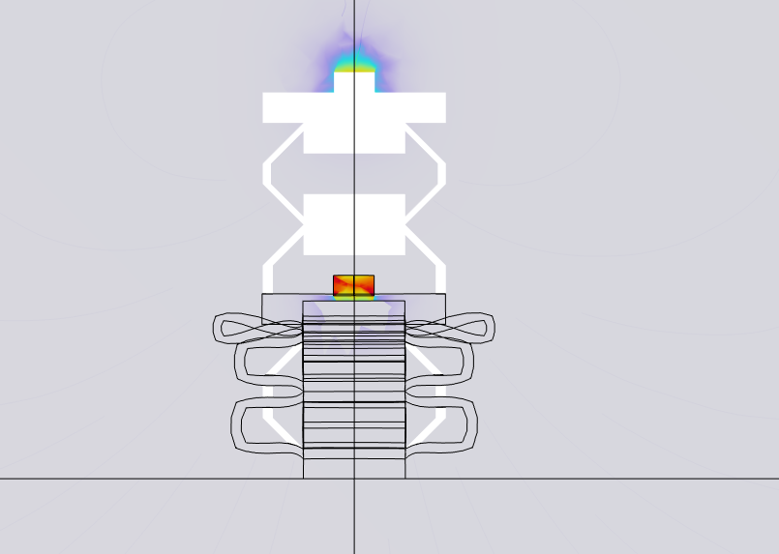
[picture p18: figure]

(a) Initial magnetic field at y disp = 0. | (b) Final magnetic field at y disp = -15 mm.

Figure 17: Magnetic flux density (mf.normB) at initial and final displacement. Note the change in field concentration at the sensor point.

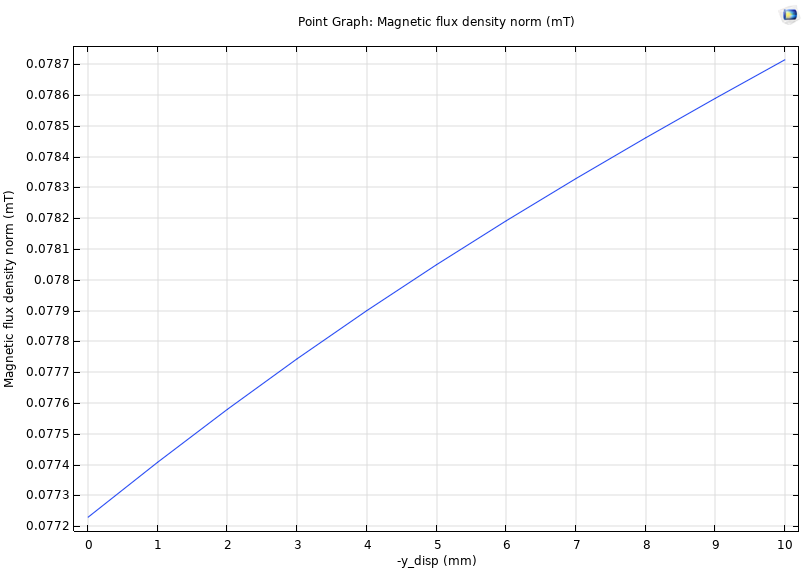
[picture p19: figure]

Figure 18: Primary result: Magnetic field strength at the magnetometer as a function of the magnet’s vertical displacement (y disp).

## 9 Evolution of Methodology and Coupling Challenges

The simulation process underwent significant iterative development to achieve the correct multiphysics coupling and reliable results. This section details the structural iterations, the challenges faced during the multiphysics coupling, and the final successful methodology implemented.

### 9.1 Challenges Encountered

Integrating the Solid Mechanics, Moving Mesh (ALE), and Magnetic Fields interfaces introduced several convergence and accuracy-related issues. Multiple strategies were evaluated before achieving a stable and physically consistent solution.

1. Dependency Error: During early attempts with a manually configured Moving Mesh interface, the solver generated an “Undefined variable solid.u” error. This occurred because the ALE interface attempted to access displacement variables before they were computed by the Solid Mechanics module.
2. Static Magnetic Field (“Ghost Magnet”) Issue: Initial simulations exhibited visible motion of the magnet domain, while the magnetic field distribution remained fixed, resulting in a near-zero response (∆B ≈ 0). The underlying cause was the lack of spatial-frame updating within the Magnetic Fields interface, which occurred because Geometric Nonlinearity was initially disabled.
3. Magnitude Discrepancy in Magnetic Field: Preliminary field results indicated intensities approximately 10³
times weaker than expected. This discrepancy was traced to a geometric misalignment introduced during CAD import, which positioned the magnet 10–50 mm away from the intended sensor origin (0, 0, 0).
4. Desired Magnetic behavior after a distance: One of the key observation was that for a particular distance our magnetometer point was not sensing the change of magnetic field (because of coupling reason), but after 7 mm movement of the magnet, it senses as required which can be seen in the figure below.
5. Mesh Discontinuity at the Magnet–Structure Interface: Applying structural deformation initially caused the magnet to detach or “float” due to the absence of shared mesh nodes at the interface—an issue arising from the use of Form Assembly instead of Form Union.

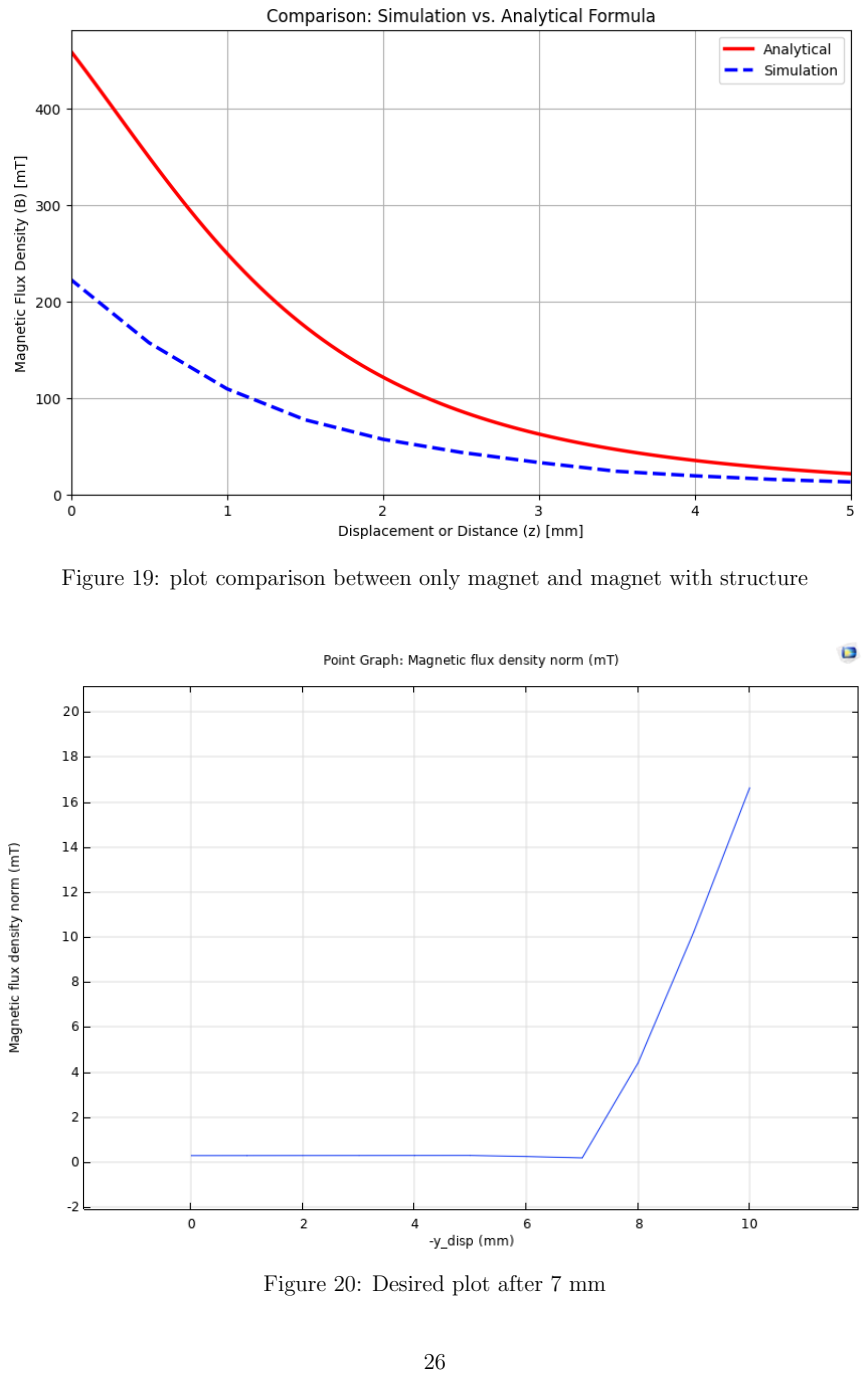
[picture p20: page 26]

Figure 19: plot comparison between only magnet and magnet with structure

Figure 20: Desired plot after 7 mm

### 9.2 Structural Designs made to evaluate the problem

To check whether is there any issue with the previous design we made three cell structures in SOLIDWORKS.

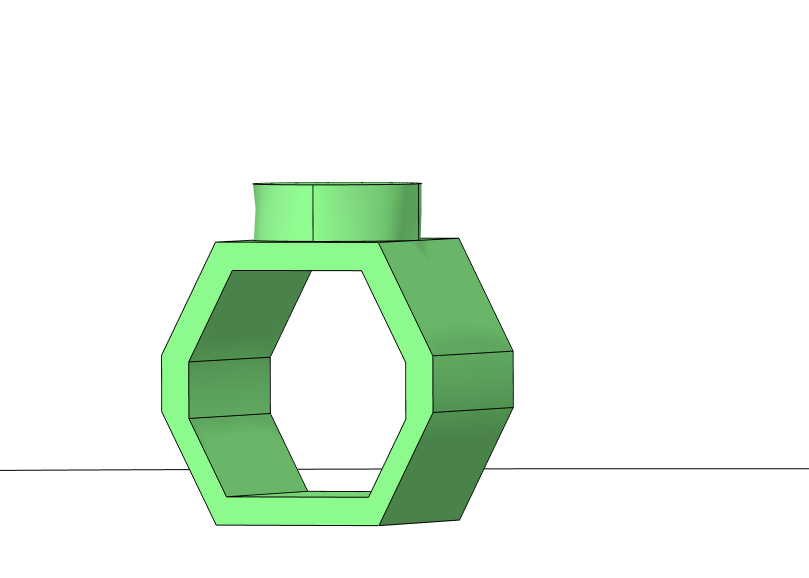
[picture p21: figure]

(a) Structure Design Iteration 1 | (b) Structure Design Iteration 2

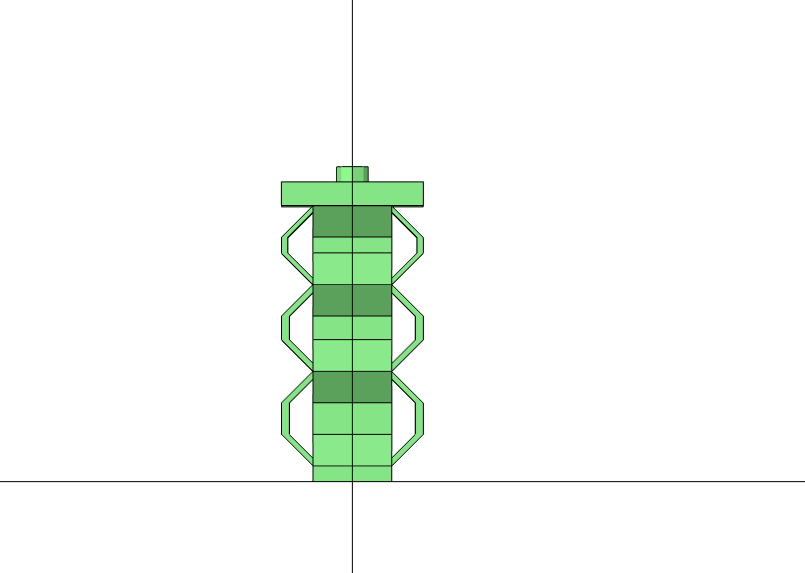
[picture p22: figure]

(c) Structure Design Iteration 3 | (d) Keeping this structure

After checking all the structures we found out that the main problem was the coupling issue of both physics so we kept our old structure for new coupling.

### 9.3 Coupling Strategies Evaluated

- Approach A: Manual Coupling Prescribing deformation in the ALE interface using solid.u. Outcome: Solver failure due to undefined variable dependencies.
- Approach B: Manual Frame Adjustment Attempting to set the Magnetic Fields interface to the Mesh (ALE) frame. Outcome: Configuration instability and persistent static magnetic fields.
- Approach C: Multiphysics Coupling Node Using the built-in Magnetic–Structure Interaction node. Outcome: Improved consistency, though sensitive to boundary condition selection.

### 9.4 Final Adopted Methodology

As the whole issue was of coupling of Solid Mechanics and Magnetic field physics, so in our latest approach we are treating the magnet and the base structure as separate identities and the prescribed displacement is applied separately on the top faces of both the identities, and for we are using Magnetomechanical Forces as coupling interface which comes under the Multiphysics section, and we are getting satisfactory results. For

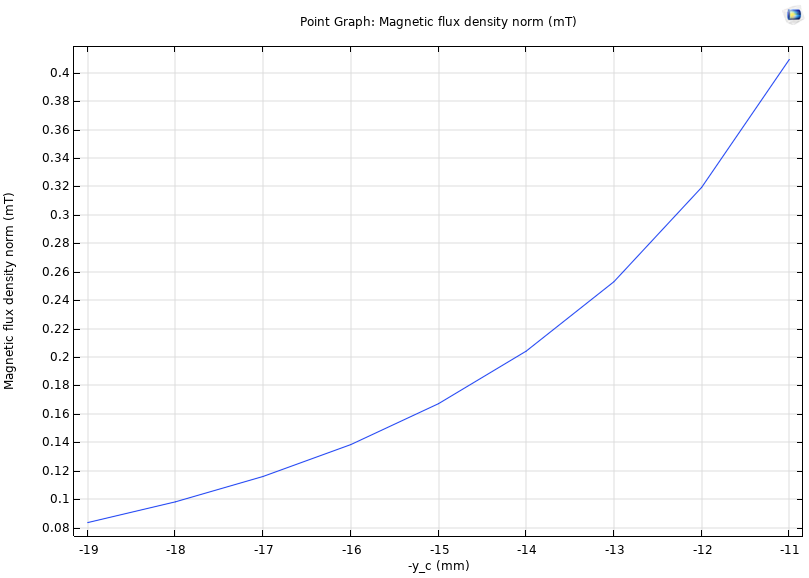
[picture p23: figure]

Figure 22: Magnetic flux density vs distance of magnet center from magnetometer

the plot below, the initial magnet position was = 19mm i.e. the top surface of structe and it moved till 11 mm from the magnetometer.

- Outcome: This ensured synchronized motion between the magnet and the deforming structure, prevented mesh inversion, and enabled accurate relative motion of the magnetic field source. The resulting magnetic-field predictions aligned closely with reported literature trends, both in magnitude and sensitivity.

## 10 Neccessary Plots for further calculations

### 10.1 Force vs Displacement

As the main objective was to calculate the force applied by external agency on the sensor so following plot shows the reaction force which at the fixed surface which will be equal to the force applied.

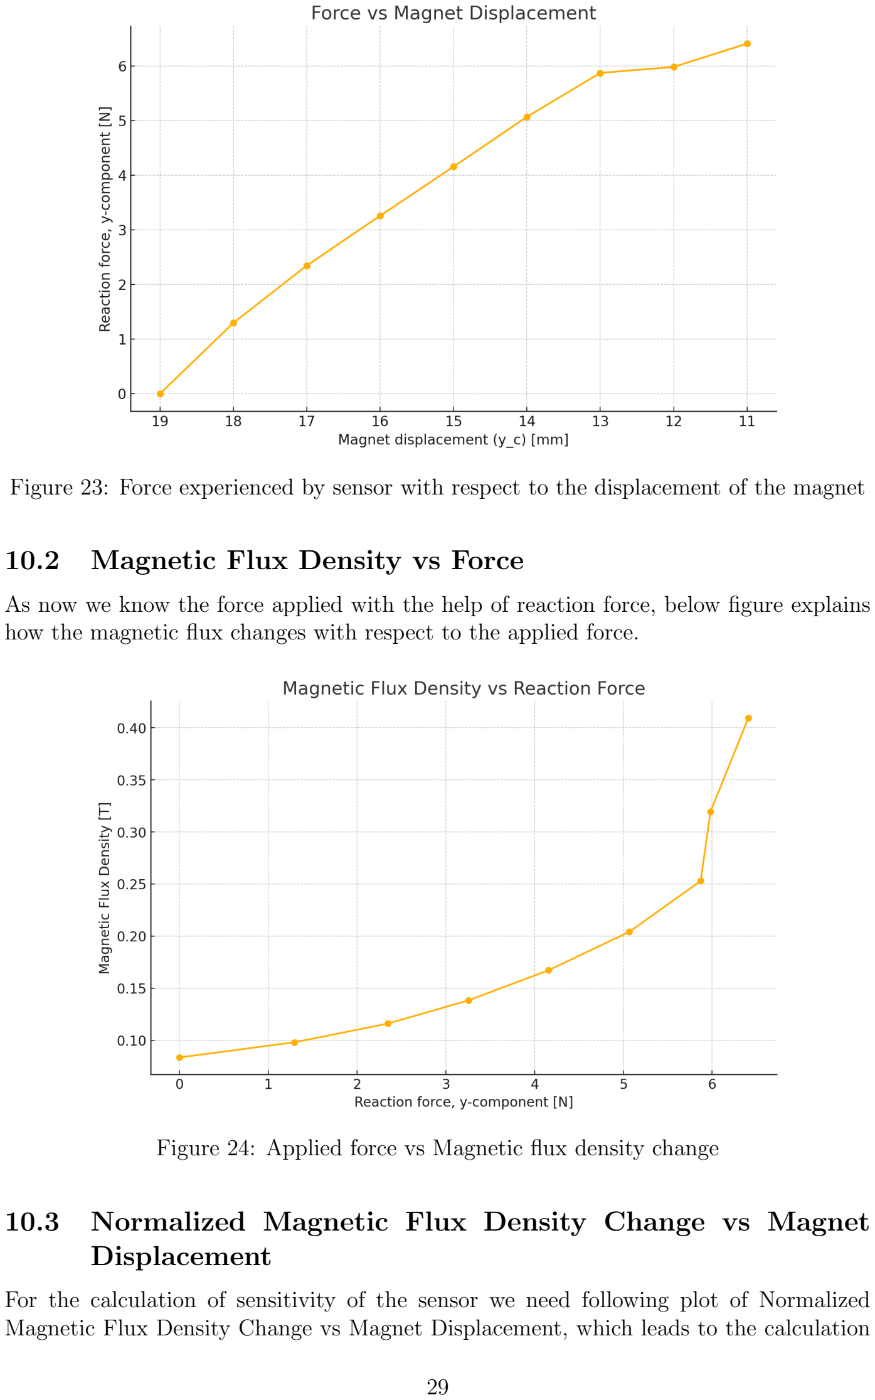
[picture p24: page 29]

Figure 23: Force experienced by sensor with respect to the displacement of the magnet

### 10.2 Magnetic Flux Density vs Force

As now we know the force applied with the help of reaction force, below figure explains how the magnetic flux changes with respect to the applied force.

Figure 24: Applied force vs Magnetic flux density change

### 10.3 Normalized Magnetic Flux Density Change vs Magnet Displacement

For the calculation of sensitivity of the sensor we need following plot of Normalized Magnetic Flux Density Change vs Magnet Displacement, which leads to the calculation

of sensitivity of structure.

Figure 25: Normalized Magnetic Flux Density Change vs Magnet Displacement

### 10.4 Normalized Magnetic Flux Density Change vs Reaction Force

To calculate the sensitivity of each layer of multilayer sensor we need following plot.

Figure 26: Normalized Magnetic Flux Density Change vs Reaction Force

### 10.5 Sensor Block Dimensions for further calculations


Figure 27: Height of each cell of Block structure

## 11 Extraction of Layer Stiffness ki and Sensitivity Si from Simulation Data

### 1. Definition of Displacement Coordinate

The COMSOL output gives the vertical coordinate of the magnet centre as yc (mm). The vertical displacement of the top layer is defined as

d = 19 mm − yc, | (28)

so that d = 0 at yc = 19 mm (no load) and d = 8 mm at yc = 11 mm (maximum simulated load).
Using this definition, the simulation points are

yc [mm] d [mm] | F [N] | ∆B/B0 [–]
19 | 0 | −0.0021 −3.63 × 10⁻⁶
18 | 1 | 1.2954 | 0.17486
17 | 2 | 2.3439 | 0.38882
16 | 3 | 3.2563 | 0.65734
15 | 4 | 4.1551 | 1.0022
14 | 5 | 5.0673 | 1.4452
13 | 6 | 5.8709 | 2.0300
12 | 7 | 5.9807 | 2.8249
11 | 8 | 6.4076 | 3.9035

### 2. Geometrical Partition into Layers

According to the design, the vertical regions of the MST block are:

- Upper support: 19 mm → 17.5 mm (magnet insertion support), corresponding to d ∈ [0, 1.5] mm.
- Cell 1 (softest): 17.5 mm → 12.5 mm, corresponding to d ∈ [1.5, 6.5] mm with thickness
dmax,1 = 17.5 − 12.5 = 5 mm. | (29)
- Cell 2 (intermediate): 12.5 mm → 7 mm, corresponding to d ∈ [6.5, 12] mm with thickness
dmax,2 = 12.5 − 7 = 5.5 mm. | (30)
- Cell 3 (stiffest): 7 mm → 1 mm, corresponding to d ∈ [12, 18] mm with thickness
dmax,3 = 7 − 1 = 6 mm. | (31)

Although the geometric partition suggests that Cell 3 starts to dominate only after d ≈ 12 mm, the structure is mechanically continuous. Therefore, even within the d = 0– 8 mm range of the present simulation, the stiffest cell experiences a small but non-zero deformation, as also qualitatively indicated by the deformation plot in Fig.16.

### 3. Stiffness and Sensitivity of Cell 1

For Cell 1 we use the two simulation points that lie well inside this layer:

yc = 17 mm (d = 2 mm), yc = 13 mm (d = 6 mm).

(a) Stiffness k1. Using Hooke’s law in the linear regime,

k1 ≈

∆F1
∆d1

=

F(d = 6 mm) − F(d = 2 mm)
| | 6 − 2
. | (32)

Substituting the force values,

∆F1 = 5.8709 N − 2.3439 N = 3.5270 N, | (33)
∆d1 = 4 mm, | (34)

gives

k1 =

| 3.5270
≈ 0.882 N/mm. | (35)

(b) Magnetic-field gradient for Cell 1. Using the same two points for ∆B/B0:
∆B
B0

′

1

≈

∆(∆B/B0)1
∆d1

=

∆B/B0|

d=6 − ∆B/B0|
d=2
6 − 2
. | (36)

Numerically,

∆(∆B/B0)1 = 2.0300 − 0.38882 = 1.64118, | (37)
∆B
B0

′

1

=

1.64118
4

≈ 0.410 mm⁻¹
. | (38)
(c) Sensitivity S1. Using the layer-specific sensitivity definition

Si =

(∆B/B0)/∆di

ki

, | (39)

we obtain for Cell 1

S1 =

0.410 mm⁻¹
0.882 N/mm ≈ 0.465 N⁻¹
. | (40)
(d) Force sensing range R1. The full geometric thickness of Cell 1 is dmax,1 = 5 mm, so from
Ri = dmax,i ki | (41)

we get
R1 = 5 mm × 0.882 N/mm ≈ 4.41 N. | (42)

### 4. Stiffness and Sensitivity of Cell 2

Within the simulated range, Cell 2 is sampled at

yc = 12 mm (d = 7 mm), yc = 11 mm (d = 8 mm).

(a) Stiffness k2.

k2 ≈

∆F2
∆d2

=

F(d = 8) − F(d = 7)
8 − 7
. | (43)

Substituting the values,

∆F2 = 6.4076 N − 5.9807 N = 0.4269 N, | (44)
∆d2 = 1 mm, | (45)

so
k2 =

0.4269
1
≈ 0.427 N/mm. | (46)
(b) Magnetic-field gradient for Cell 2.
∆B
B0

′

2

≈

∆B/B0|

d=8 − ∆B/B0|
d=7
8 − 7
. | (47)

Numerically,

∆(∆B/B0)2 = 3.9035 − 2.8249 = 1.0786, | (48)
∆B
B0

′
=

1.0786
1

≈ 1.079 mm⁻¹
. | (49)

(c) Sensitivity S2.

S2 =

(∆B/B0)

′
2
k2

=

1.079 mm⁻¹
0.427 N/mm ≈ 2.53 N⁻¹
. | (50)
(d) Force sensing range R2. Using the design thickness of Cell 2, dmax,2 = 5.5 mm:
R2 = dmax,2 k2 = 5.5 mm × 0.427 N/mm ≈ 2.35 N. | (51)

### 6. Stiffness and Sensitivity of Cell 3 (Assuming 1 mm deformation)

Although the simulation range only directly compresses the structure down to yc = 11 mm, visual inspection of the deformation field confirms that the stiffest cell (Cell 3) undergoes a small but non-zero deformation during loading. To include its contribution, we assume an effective deformation

∆d

eff
3 = 1 mm. | (52)

The maximum applied force from simulation is

Fmax = 6.4076 N. | (53)
(a) Effective stiffness of Cell 3 Using Hooke’s law,

k

eff
3 =

Fmax
∆d

eff
3

=

6.4076 N
1 mm
≈ 6.41 N/mm. | (54)
(b) Magnetic field gradient of Cell 3 The associated normalized magnetic field change in the high-force region is

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
= 3.9035 − 2.8249 = 1.0786. | (55)

Thus, the magnetic gradient is
∆B
B0

′

3

=

1.0786
1 mm

= 1.0786 mm⁻¹
. | (56)
(c) Sensitivity of Cell 3

S3 =

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
1.0786 mm⁻¹
6.41 N/mm ≈ 0.168 N⁻¹
. | (57)
(d) Force sensing range of Cell 3 The geometric compression capacity of Cell 3 is:
| dmax,3 = 6 mm. | (58)

Therefore,

R3 = dmax,3 · k

eff
3 | = 6 mm · 6.41 N/mm ≈ 38.46 N. | (59)

Summary of full multi-range performance

Layer | ki (N/mm) Si (N⁻¹
) Ri (N)
Cell 1 (softest) | 0.882 | 0.465 | 4.41
Cell 2 (mid) | 0.427 | 2.53 | 2.35
Cell 3 (stiffest) | 6.41 | 0.168 | 38.46

These results clearly demonstrate a multi-range force sensing capability:

- High sensitivity at low forces (Cell 1)
- Very high sensitivity in intermediate regime (Cell 2)
- Large force-range endurance with lower sensitivity (Cell 3)

## 12 Comparison Plot

1 | import numpy as np
2 | import matplotlib.pyplot as plt

3
4 | Br = 1.3 | # Remanent flux density (T)
5 | L = 0.001 | # Magnet length/height (m)
6 | R = 0.001 | # Magnet radius (m)

7
8 z_analytical_m = np.linspace(0.011, 0.019, 200)

9
10 | term1 = (L + z_analytical_m) / np.sqrt(R**2 + (L + z_analytical_m)**2)
11 | term2 = z_analytical_m / np.sqrt(R**2 + z_analytical_m**2)
12 | B_analytical_T = (Br / 2) * (term1 - term2)

13
14 | x_analytical = z_analytical_m * 1000
15 | y_analytical = B_analytical_T * 1000

16
17 | x_simulation = np.array([19., 18., 17., 16., 15., 14., 13., 12., 11.])
18 | y_simulation = np.array([0.083487, 0.098086, 0.11595, 0.13837, 0.16716,
19 | | 0.20414, 0.25296, 0.31933, 0.40938])

20
21 | plt.figure(figsize=(10,6))
22 | plt.plot(x_analytical, y_analytical, 'r-', lw=2.0, label='Analytical')
23 | plt.plot(x_simulation, y_simulation, 'bo--', lw=1.5, label='Simulation')
24 | plt.xlabel('Displacement (z) [mm]')
25 | plt.ylabel('B [mT]')
26 | plt.title('Analytical vs Simulation')
27 | plt.legend()
28 | plt.grid(True)
29 | plt.xlim(11, 19)
30 | plt.ylim(bottom=0)
31 | plt.show()


Figure 28: Comparison plot of magnetic flux density for single magnet vs magnet with structure from 19mm(top of structure) to 11mm

## 13 Future Work

Future work will concentrate on experimentally validating the simulation results and extending the demonstrated methodology toward application-specific implementations. The primary next steps include:

1. Experimental Validation:
- Fabricate physical prototypes of the MST sensor (e.g., via 3D printing using TPU).
- Conduct controlled laboratory tests to measure force-displacement and magnetic-field responses.
- Compare experimental data with simulation predictions and refine material models and boundary conditions.
2. Comprehensive Performance Characterization:
- Quantify sensitivity, linearity, hysteresis, dynamic range, and repeatability for each sensitivity regime.
- Evaluate temperature and environmental robustness, and characterize sensor drift over time.
3. Design Optimization:
- Perform multi-objective optimization of geometric and material parameters to improve sensitivity–range trade-offs.
- Explore alternative metamaterial architectures and graded/staged stiffness configurations to achieve tailored sensitivity profiles.
4. Transduction and Integration:
- Investigate alternative transduction mechanisms and hybrid sensing (e.g., magnetic combined with capacitive or piezoresistive elements).
- Develop compact magnet and magnetometer housings and integrate readout electronics for real-time sensing.
5. Application-Specific Prototyping and Testing:
- Prototype sensor integration into robotic end-effectors, prosthetic devices, and human-machine interfaces.
- Perform system-level tests (grip tasks, texture recognition, impact monitoring) to demonstrate practical utility.
6. Scaling and Manufacturability:
- Investigate manufacturing scalability (e.g., batch 3D printing, molding) and tolerances for reproducible performance.
- Assess cost, durability, and long-term reliability for real-world deployment.

Together, these future directions aim to transition the MST sensor concept from simulationvalidated designs to robust, deployable sensing systems with demonstrable benefits in robotics, prosthetics, and safety-critical applications.

## 14 Conclusion

This project presents a comprehensive approach to developing Multi-sensitivity Soft Tactile (MST) sensors based on flexible mechanical metamaterials. The mathematical framework established from the literature provides a solid foundation for systematic design and optimization of sensors with programmable sensitivity characteristics. The current phase focused on validating the theoretical approach through detailed COMSOL Multiphysics simulations, incorporating design parameters and performance specifications from the literature. The simulation-based validation was crucial for understanding the underlying physics and optimizing design parameters for specific applications. The systematic methodology integrating mathematical modeling, CAD design, and multi-physics simulation provides a robust framework for developing application-specific tactile sensors. The demonstrated multi-sensitivity capability represents a significant advancement in tactile sensing technology with broad applicability across robotics, prosthetics, and human-machine interaction fields.

## References

[1] A. Mohammadi, H. Kim, and R. Pfeifer, Soft Magnetic Tactile Sensors: Modeling and Characterization, Scientific Reports, 2021.
[2] K. Bertoldi, V. Vitelli, J. Christensen, and M. van Hecke, Flexible Mechanical Metamaterials, Nature Reviews Materials, 2017.
[3] T. Tomo, et al., Design and Calibration of Magnetic Soft Tactile Sensors, Sensors, 2016.
[4] H. Wang, et al., Magneto–Mechanical Coupled Sensors for Robotics Applications, Sensors and Actuators A: Physical, 2016.
[5] COMSOL Multiphysics® Reference Manual, Version 6.1.
[6] NdFeB N35 Permanent Magnet Datasheet, Physical and Magnetic Properties.
[7] M. Kadic, T. B¨uckmann, R. Schittny, and M. Wegener, Metamaterials Beyond Electromagnetism, Reports on Progress in Physics, 2013.

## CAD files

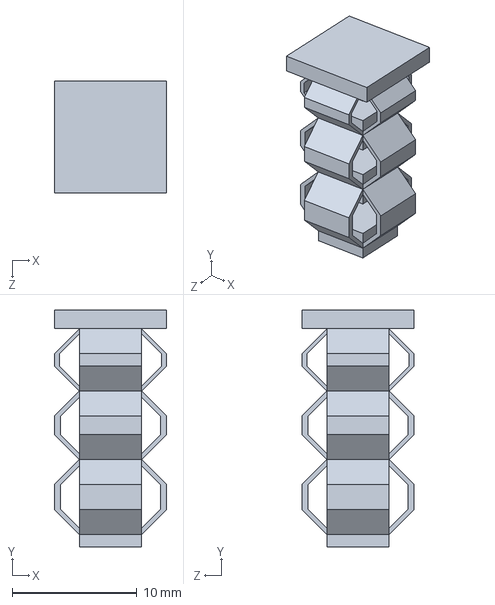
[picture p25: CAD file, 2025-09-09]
Sensor cad/Part2.SLDPRT
9.00 x 19.0 x 9.00 mm

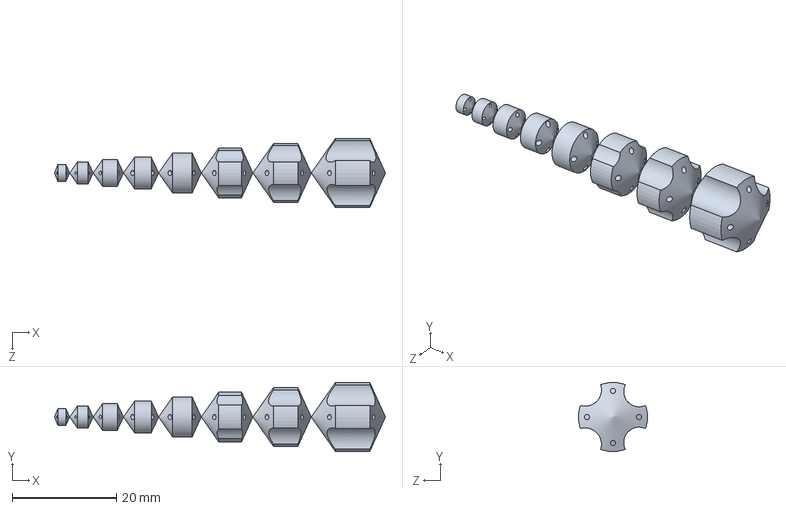
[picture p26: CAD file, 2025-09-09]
Solidworks files/Part1.SLDPRT
63.4 x 13.2 x 13.2 mm

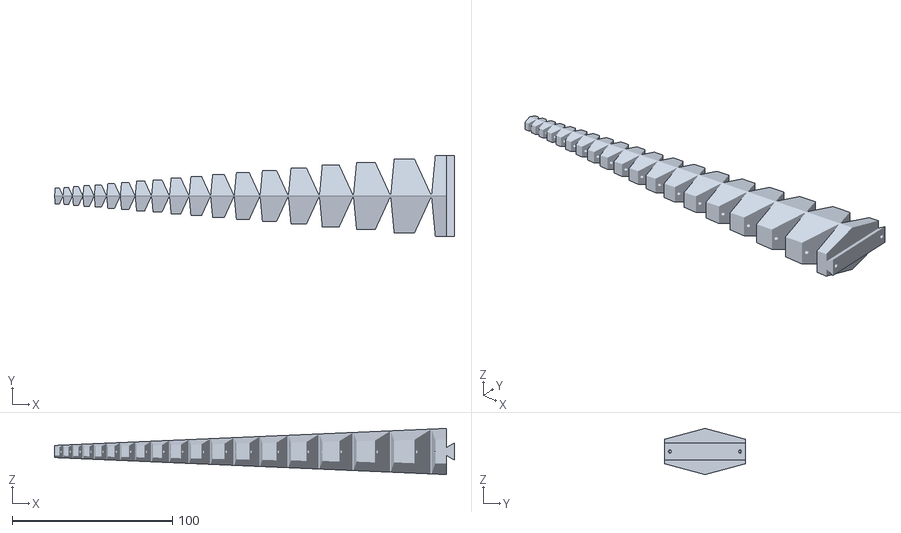
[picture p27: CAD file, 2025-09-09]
SolidWorks Final/1-s2.0-S2666998624006033-mmc2/Data S1/2-cable SpiRob.STL
249.7 x 50.6 x 28.8

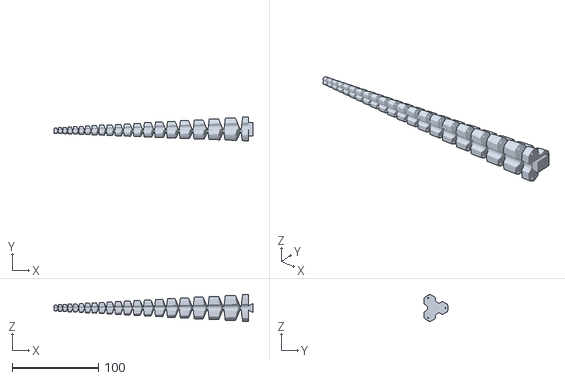
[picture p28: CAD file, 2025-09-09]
SolidWorks Final/1-s2.0-S2666998624006033-mmc3/Data S2/3-cable SpiRob.STL
231.3 x 27.8 x 31.4

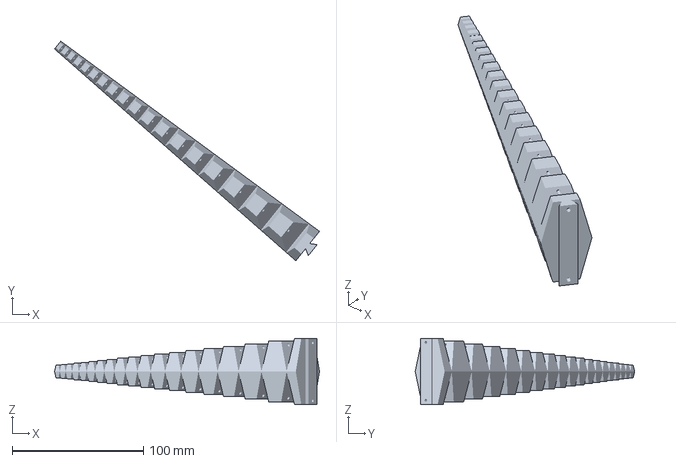
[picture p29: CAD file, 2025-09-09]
SolidWorks Final/1-s2.0-S2666998624006033-mmc4/Data S3/TPU 95A.3mf
202.1 x 167.5 x 50.6 mm

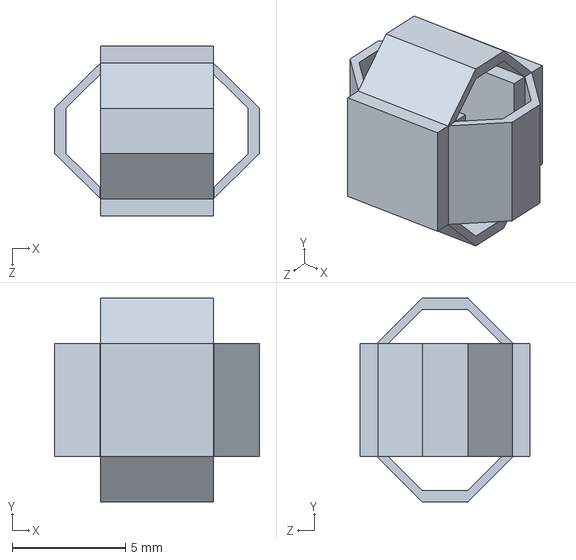
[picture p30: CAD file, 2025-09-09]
Sensor cad/Part1.SLDPRT
9.04 x 8.98 x 7.48 mm

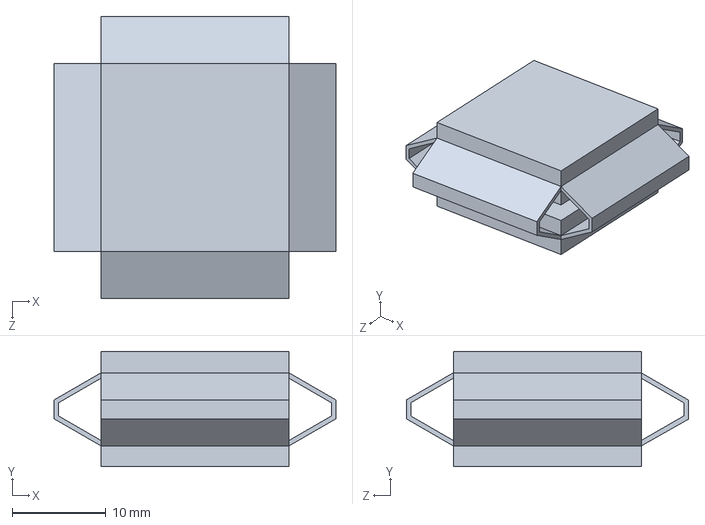
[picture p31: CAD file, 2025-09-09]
Sensor cad/Part3.SLDPRT
30.0 x 12.3 x 30.1 mm

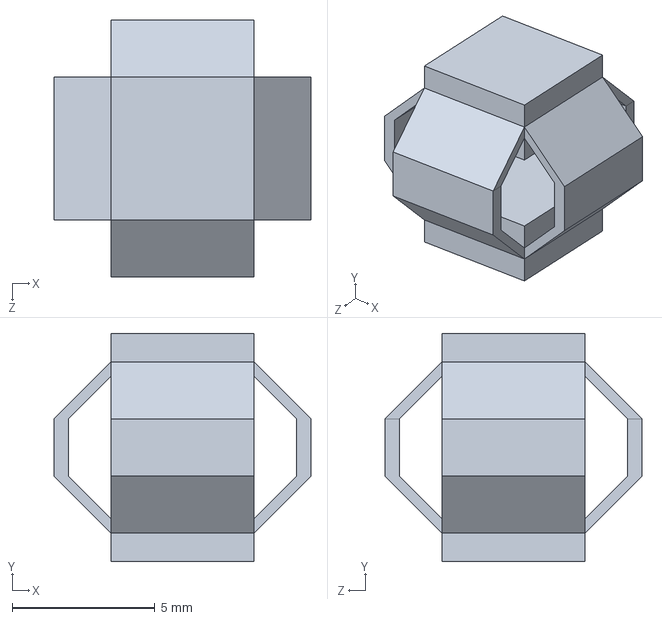
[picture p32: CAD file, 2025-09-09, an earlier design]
Sensor cad/Part2 - Copy.SLDPRT
9.00 x 8.00 x 9.00 mm
